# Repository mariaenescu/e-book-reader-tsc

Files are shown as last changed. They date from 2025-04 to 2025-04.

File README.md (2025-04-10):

Enescu Maria - 331CA

# OpenBook Project - E-Book Reader

OpenBook is a compact device designed for digital reading. Based on the ESP32-C6 microcontroller, OpenBook includes integrated Wi-Fi connectivity.
It features a 7.5" e-Paper display and an 1800mAh battery, offering extended battery life.

--- 

## 3D Visualizations
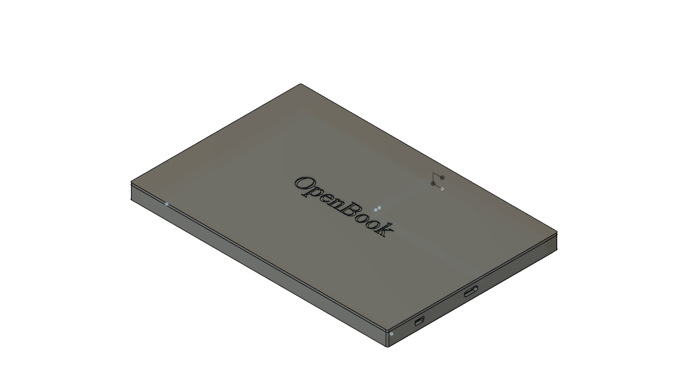
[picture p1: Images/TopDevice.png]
P1

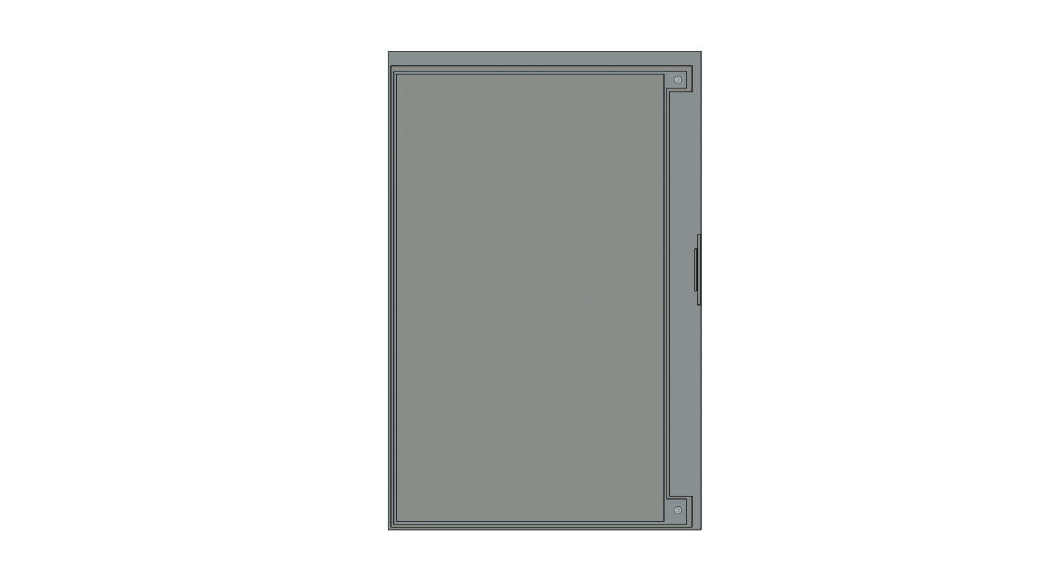
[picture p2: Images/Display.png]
P2

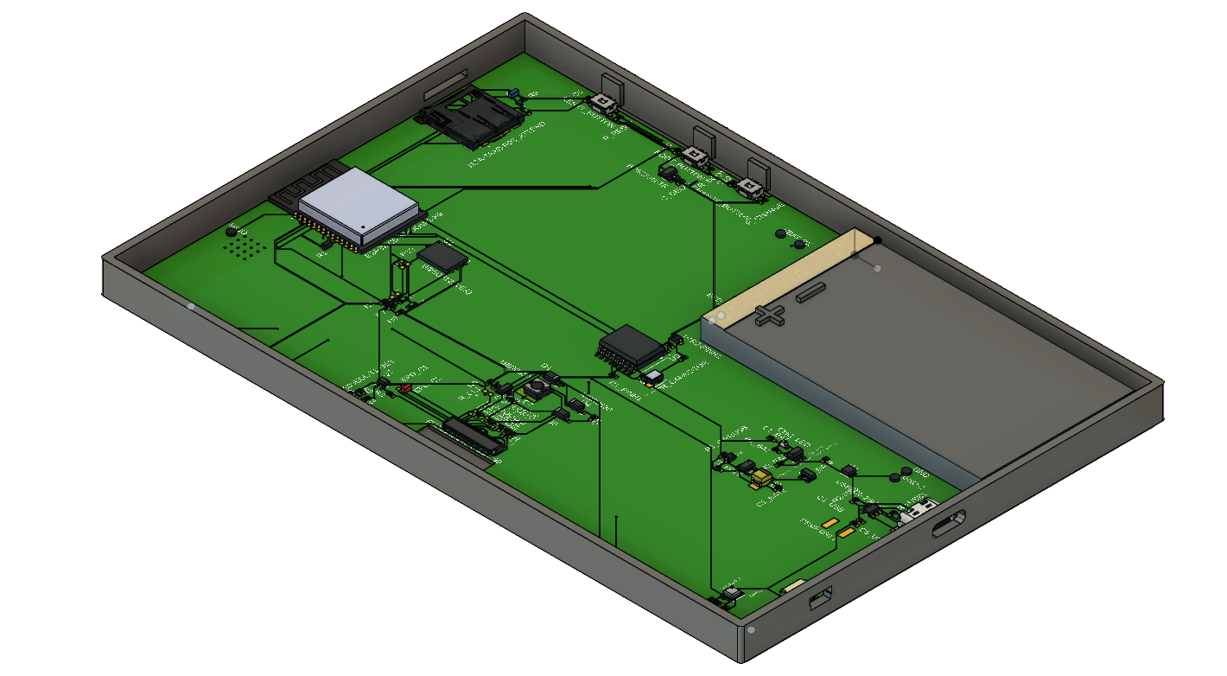
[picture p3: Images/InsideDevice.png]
P3


---
## Block Diagram
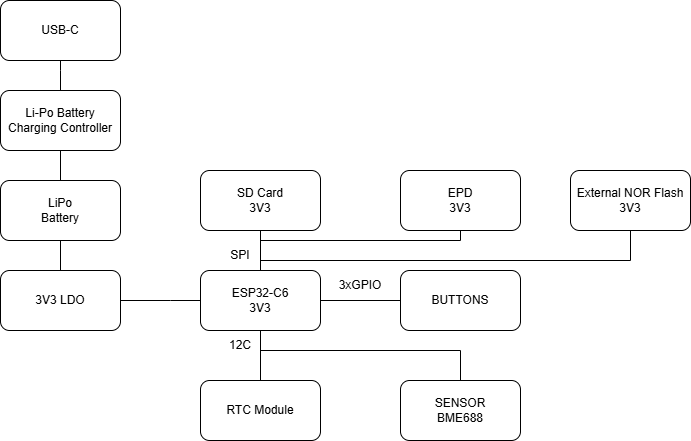
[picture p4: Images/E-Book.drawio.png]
Diagrama bloc


---

## Main Components Overview

**Microcontroller – ESP32-C6-WROOM-1-N8**  
Acts as the main processing unit of the system, responsible for wireless communication, power management, and control of all peripherals. It uses SPI, I2C, and GPIO interfaces to interact with external modules.

**E-Paper Display – 7.5” Waveshare**  
Displays e-book content using ultra-low power. It is controlled via SPI and connected through MOSI, MISO, SCK, CS, DC, RST, and BUSY pins.

**MicroSD Card – 112A-TAAR-R03**  
Used for storing e-books and data files. Communicates with the ESP32 via the SPI interface and supports FAT32 format up to 32GB.

**NOR Flash Memory – W25Q512JVEIQ**  
Provides external non-volatile memory for storing firmware or additional data. It connects via SPI and supports fast read/write operations.

**Real-Time Clock – DS3231SN**  
Ensures accurate timekeeping, even when the device is off. It uses the I2C protocol and provides a 32KHz output and interrupt signal.

**Environmental Sensor – BME688**  
Measures temperature, humidity, pressure, and gas levels. Communicates via I2C and is powered through a dedicated I2C power pin.

**Battery – Cellevia LP584174 (Li-Po 3.7V, 1800mAh)**  
Powers the system when disconnected from USB. Provides stable operation and extended autonomy.

**Power Management – MCP73831 & AMS1117**  
MCP73831 handles Li-Po charging via USB-C. AMS1117 regulates the output voltage to 3.3V required by the ESP32 and peripherals.

**USB-C Connector – USB4110-GF-A**  
Used for charging the battery and data transfer. Protected by ESD varistor (PFMF.050.1) and Schottky diode for reverse polarity.

**Buttons – Tactile Push Buttons (3x)**  
Used for boot, reset, and mode change. Connected to GPIOs for user input and state control.

---

## Bill of Materials
| Compound | Purchase | Datasheet |
|---|---|---|
| Buton | [Click here](https://componentsearchengine.com/prices/TSP1C-RA?manufacturer=KNITTER-SWITCH) | https://docs.rs-online.com/1fd0/0900766b80e2c247.pdf |
| Condensator 100nF | [Click here](https://ro.mouser.com/ProductDetail/KYOCERA-AVX/04026D104KAT2A?qs=LLG2yGGJ5NhILwMziGI8Xg%3D%3D) | https://www.mouser.com/catalog/supplier/library/pdf/AVXSurfaceMountCeramic.pdf |
| CPH3225A(C10_SUPERCAP) | [Click here](https://ro.mouser.com/ProductDetail/Seiko-Semiconductors/CPH3225A?qs=3etwrb1wR%252BhUOph6lAO7eg%3D%3D) | https://ro.mouser.com/datasheet/2/360/Seiko_Instruments_MicroBattery_E_20230330_2024Jan_-3561061.pdf |
| Condensator 4.7uF | [Click here](https://ro.mouser.com/ProductDetail/KEMET/C0402C475M7PACTU?qs=SzIX745sIXFB9Q9KfZhc4g%3D%3D) | https://ro.mouser.com/datasheet/2/447/KEM_C1006_X5R_SMD-3316465.pdf |
| Tantalum Condensator 100uF | [Click here](https://ro.mouser.com/ProductDetail/KYOCERA-AVX/TAJW107M010RNJ?qs=Wtp%252Bf%2FAeVqIH8v1VxV%252B1Rg%3D%3D) | https://ro.mouser.com/datasheet/2/40/TAJ-3165264.pdf |
| Condensator 1uF | [Click here](https://ro.mouser.com/ProductDetail/KYOCERA-AVX/04026D105KAT2A?qs=LLG2yGGJ5NgAzk5fb%252BnzGQ%3D%3D) | https://ro.mouser.com/datasheet/2/40/cx5r_KGM-3223198.pdf |
| Condensator 10uF | [Click here](https://www.digikey.com/en/products/detail/venkel/C0402X5R100-106MNP/12327194) | https://venkelecd.com/partnumber/datasheet/C0402X5R100-106MNP) |
| CHG_LED | [Click here](https://www.kingbrightusa.com/distyPNInv.asp?sltSearch=distyInv&match=1&txtPartNo=APHM1608ECT) | https://www.kingbrightusa.com/images/catalog/SPEC/APHM1608ECT.pdf |
| USBLC6-2SC6Y | [Click here](https://ro.mouser.com/ProductDetail/STMicroelectronics/USBLC6-2SC6Y?qs=gNDSiZmRJS%2FOgDexvXkdow%3D%3D) | https://ro.mouser.com/datasheet/2/389/usblc6_2sc6y-1852505.pdf |
| PGB1010603MR | [Click here](https://ro.mouser.com/ProductDetail/Littelfuse/PGB1010603MR?qs=gu7KAQ731URLg4GSnNNN7Q%3D%3D) | https://www.littelfuse.com/assetdocs/pulseguard-esd-suppressors-pgb1-datasheet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 |
| SD0805S020S1R0 | [Click here](https://ro.mouser.com/ProductDetail/KYOCERA-AVX/SD0805S020S1R0?qs=jCA%252BPfw4LHbpkAoSnwrdjw%3D%3D) | https://ro.mouser.com/datasheet/2/40/schottky-3165252.pdf |
| MBR0530 | [Click here](https://ro.mouser.com/ProductDetail/onsemi/MBR0530T1G?qs=3JMERSakeboS%2FFOxJUMWeg%3D%3D) | https://www.onsemi.com/download/data-sheet/pdf/mbr0530t1-d.pdf |
| Condensator 1uF/50V | [Click here](https://ro.mouser.com/ProductDetail/KYOCERA-AVX/06035D105MAT2A?qs=k4kUdCzLgS5%252BURKe1SOIeQ%3D%3D) | https://ro.mouser.com/datasheet/2/40/cx5r_KGM-3223198.pdf |
| Condensator 0.1uF/50V | [Click here](https://ro.mouser.com/ProductDetail/KYOCERA-AVX/04025C104JAT2A?qs=yqaQSyyJnNjAUYBPnTRwrw%3D%3D) | https://ro.mouser.com/datasheet/2/40/AutoMLCC-2952695.pdf |
| BD5229G-TR | [Click here](https://ro.mouser.com/ProductDetail/ROHM-Semiconductor/BD5229G-TR?qs=4kLU8WoGk0vvnhrrYwdszw%3D%3D) | https://fscdn.rohm.com/en/products/databook/datasheet/ic/power/voltage_detector/bd52xxg-e.pdf |
| XC6220A331MR-G | [Click here](https://ro.mouser.com/ProductDetail/Torex-Semiconductor/XC6220A331MR-G?qs=AsjdqWjXhJ8ZSWznL1J0gg%3D%3D) | https://ro.mouser.com/datasheet/2/760/xc6220-3371556.pdf |
| FH34SRJ-24S-0.5SH_99_ | [Click here](https://ro.mouser.com/ProductDetail/Hirose-Connector/FH34SRJ-24S-0.5SH99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) | https://ro.mouser.com/datasheet/2/185/FH34SRJ_24S_0_5SH_99__CL0580_1255_6_99_2DDrawing_0-1615044.pdf |
| USB4110-GF-A | [Click here](https://ro.mouser.com/ProductDetail/GCT/USB4110-GF-A?qs=KUoIvG%2F9IlYiZvIXQjyJeA%3D%3D) | https://ro.mouser.com/datasheet/2/837/GCT_USB4110_Product_Drawing___20k_cycles-3455479.pdf |
| QWIIC_RIGHT_ANGLE | [Click here](https://ro.mouser.com/ProductDetail/JST-Commercial/SM04B-SRSS-TBLFSN?qs=cdbOS8ANM9B3FdyA6cNU2A%3D%3D) | https://ro.mouser.com/datasheet/2/564/eSR_SZ-3476820.pdf |
| 112A-TAAR-R03_ATTEND | [Click here](https://www.tme.eu/ro/details/mcc-sdmicro/conectori-pentru-cartele/attend/112a-taar-r03/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) | https://www.attend.com.tw/data/download/file/112A-TAAR-R03.pdf |
| Bobina | [Click here](https://ro.mouser.com/ProductDetail/Wurth-Elektronik/744043680?qs=PGXP4M47uW6VkZq%252BkzjrHA%3D%3D) | https://www.we-online.com/components/products/datasheet/744043680.pdf |
| MCP73831 | [Click here](https://ro.mouser.com/ProductDetail/Microchip-Technology/MCP73831T-2ATI-OT?qs=yUQqVecv4qsZbioEUu%252B83g%3D%3D) | https://ro.mouser.com/datasheet/2/268/MCP73831_Family_Data_Sheet_DS20001984H-3441711.pdf |
| PFMF.050.1 | [Click here](https://ro.mouser.com/ProductDetail/Schurter/PFMF.050.2?qs=1auRipcfynCums5v1iucSA%3D%3D) | https://ro.mouser.com/datasheet/2/358/typ_PFMF-1275918.pdf |
| DMG2305UX-7 | [Click here](https://ro.mouser.com/ProductDetail/Diodes-Incorporated/DMG2305UX-7?qs=L1DZKBg7t5F%2FNBHrjfxC%252Bg%3D%3D) | https://www.diodes.com/assets/Datasheets/DMG2305UX.pdf |
| SI1308EDL-T1-GE3 | [Click here](https://ro.mouser.com/ProductDetail/Vishay-Semiconductors/SI1308EDL-T1-GE3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) | https://www.vishay.com/docs/63399/si1308edl.pdf |
| Rezistenta 10K | [Click here](https://www.digikey.com/en/products/detail/venkel/CR0402-10W-102JT/12332774) | https://data.venkel.com/documents/cr-series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.) |
| Rezistenta 200 | [Click here](https://ro.mouser.com/ProductDetail/Vishay-Beyschlag/MCS0402MD2000BE100?qs=3SvaY9RawMJNVte4F12%252BZQ%3D%3D) | https://www.vishay.com/docs/28952/mcs0402at-mct0603at-mcu0805at-mca1206at.pdf |
| Rezistenta 100K | [Click here](https://www.digikey.com/en/products/detail/venkel/CR0402-16W-1003FT/12328296) | https://octopart.com/datasheet/cr0402-16w-1003ft-venkel-16112934) |
| Rezistenta 2.2 | [Click here](https://www.digikey.com/en/products/detail/venkel/TFCR0402-16W-C-1002BT/12331302) | https://data.venkel.com/documents/tfcr-series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.) |
| Rezistenta 5K1 | [Click here](https://ro.mouser.com/ProductDetail/YAGEO/RT0402BRD075K1L?qs=gY0y7AQI9SOxpEAvlEsiTQ%3D%3D) | https://ro.mouser.com/datasheet/2/447/PYu_RT_1_to_0_01_RoHS_L_15-3461507.pdf |
| Rezistenta 2K | [Click here](https://ro.mouser.com/ProductDetail/Bourns/CR0402AFX-2001GLF?qs=GedFDFLaBXEKjamDtfYtIQ%3D%3D) | https://ro.mouser.com/datasheet/2/54/cr_a-1858337.pdf |
| Rezistenta 0.47 | [Click here](https://ro.mouser.com/ProductDetail/Vishay-Beyschlag/MMA02040C4707JB000?qs=YmMt7wOBEV42V6C1Rc7zpg%3D%3D) | https://www.vishay.com/docs/28713/melfprof.pdf |
| Rezistenta 15 | [Click here](https://ro.mouser.com/ProductDetail/YAGEO/RT0402FRE0715RL?qs=BXCcY9r%252B08DFFpLSkPOIqQ%3D%3D) | https://ro.mouser.com/datasheet/2/447/PYu_RT_1_to_0_01_RoHS_L_15-3461507.pdf |
| BME688 | [Click here](https://ro.mouser.com/ProductDetail/Bosch-Sensortec/BME688?qs=IS%252B4QmGtzzqQoVDscqwx3A%3D%3D) | https://ro.mouser.com/datasheet/2/783/bst_bme688_fl000-2307034.pdf |
| W25Q512JVEIQ | [Click here](https://ro.mouser.com/ProductDetail/Winbond/W25Q512JVEIQ?qs=l7cgNqFNU1jw6svr3at6tA%3D%3D) | https://ro.mouser.com/datasheet/2/949/Winbond_W25Q512JV_Datasheet-3240039.pdf |
| ESP32-C6-WROOM-1-N8 | [Click here](https://ro.mouser.com/ProductDetail/Espressif-Systems/ESP32-C6-WROOM-1-N8?qs=8Wlm6%252BaMh8ST02Gmwp74cw%3D%3D) | https://ro.mouser.com/datasheet/2/891/Espressif_ESP32_C6_WROOM_1__Datasheet_V0_1_PRELIMI-3239987.pdf |
| DS3231SN# | [Click here](https://ro.mouser.com/ProductDetail/Analog-Devices-Maxim-Integrated/DS3231SN?qs=1eQvB6Dk1vhUlr8%2FOrV0Fw%3D%3D) | https://ro.mouser.com/datasheet/2/609/DS3231-3421123.pdf |
| MAX17048G+T10 | [Click here](https://ro.mouser.com/ProductDetail/Analog-Devices-Maxim-Integrated/MAX17048G%2bT10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) | https://ro.mouser.com/datasheet/2/609/MAX17048_MAX17049-3469099.pdf |
---

## Hardware Functionality Description

The project uses the `ESP32-C6-WROOM-1-N8` microcontroller, which integrates **BLE 5** and **Wi-Fi 6** for fast and efficient communication.
The system is powered by a **3.7V Li-Po battery** with a capacity of 1800mAh (`Cellevia LP584174`).
Battery charging is managed by the `TP4056` module via a `USB-C` connector, and the constant `3.3V` required by the system is provided by an `AMS1117` voltage regulator.
The `ESP32-C6` microcontroller controls the entire system through standard **SPI**, **I2C**, and **GPIO** interfaces, as follows:
1. The `7.5" Waveshare e-Paper Display` (800x480 resolution) is connected via SPI.
2. The `SD Card` and `external NOR Flash` memory are also connected via SPI for data storage.
3. The `RTC (DS3231SN)` and `environmental sensor (BME688)` are connected via **I2C**, enabling precise real-time measurements.
4. **GPIO connections** allow control of the `RESET` and `BOOT` functions, and the **Qwiic/Stemma QT** interface supports additional sensor expansion.
5. For debugging, there are dedicated Test Pads for UART communication (`TX/RX`).

---

##  Pinii ESP32-C6
| Pin ESP32-C6 | GPIO | Job | Connected to |
|---|---|---|---|
| EN | - | RESET | Reset hardware |
| IO0 | GPIO0 | INT RTC | Intrerupere RTC |
| IO1 | GPIO1 | 32KHZ | Semnal 32kHz RTC |
| IO2 | GPIO2 | MISO | SPI MISO (Date citite) |
| IO3 | GPIO3 | EPD BUSY | Semnal ocupat Display  |
| IO4 | GPIO4 | SS_SD | Chip select SD Card |
| IO5 | GPIO5 | EPD_DC | Comanda/Date Display |
| IO6 | GPIO6 | SCK | SPI Clock |
| IO7 | GPIO7 | MOSI | SPI MOSI (Date trimise)|
| IO8 | GPIO8 | IO/BOOT | Boot mode selection |
| IO9 | GPIO9 | - | Neconectat |
| IO10 | GPIO10 | - | Neconectat |
| IO11 | GPIO11 | EPD_CS | Chip Select Display |
| IO12 | GPIO12 | FLASH_CS | Chip Select Flash |
| IO13 | GPIO13 | USB D- | Linie USB D- |
| IO14 | GPIO14 | USB D+ | Linie USB D+ |
| IO15 | GPIO15 | IO/CHANGE | Buton schimbare mod |
| IO16 | GPIO16/TX | TX | UART Debug TX |
| IO17 | GPIO17/RX | RX | UART Debug RX |
| IO18 | GPIO18 | RTC_RST | Reset RTC |
| IO19 | GPIO19 | I2C PW | Alimentare senzor I2C  |
| IO20 | GPIO20 | EPD_3V3_C | Control 3.3V Display |
| IO21 | GPIO21/SDA  | SDA | I2C Date |
| IO22 | GPIO22/SCL  | SCL | I2C Clock |
| IO23 | GPIO23 | EPD_RST | Reset Display |
---

## Project Implementation:
      
`The schematic` was created according to the requirement PDF, using symbols from the provided library and verified using 
the `ERC` file. Warnings were avoided, and remaining errors were accepted as non-critical.
During the `PCB` design phase, all components were placed exclusively on the `Top Layer`, following mechanical and dimensional recommendations.
Both the `ESP32 antenna area` and the `buttons` were cut out from the PCB outline.
`Routing` was performed using the Autorouter, with a 100% routing weight and minimum via size.
A `ground plane` was created on both layers (Bottom and Top).
`Via stitching` was added near the ESP32 component in a free area, avoiding routing traces.
Each component name is marked with `TopSilkscreen`.
Each component has an associated 3D model, either designed (TPs, battery, and display) or imported from external libraries.
The 3D models were created using exact dimensions from the provided datasheets and can be viewed in the `Images/` folder.
Later, I positioned the 3D model of the PCB, the battery, and the display inside the case.
A video has also been added in `Images/` to visualize the 3D placement of all components for the complete E-Book.

---

### Issues Encountered:

- After importing each 3D component, I noticed several routing errors and value mismatches appearing on the PCB—
  errors that did not exist before using `Push to 3D PCB`. After adding the 3D components, I attempted to re-route to fix these issues.
- I encountered problems with 3D component placement. Although all 3D models were imported, not all of them appeared on the 3D PCB.
- In **Fusion 360**, `Push to 3D PCB` sometimes desynchronized component labels and layers. Also, not all components kept their footprints aligned after 3D model imports, requiring manual corrections.
- I also had to ensure no 90° trace angles were present, per assignment constraints — which was hard to maintain while autorouting.

---

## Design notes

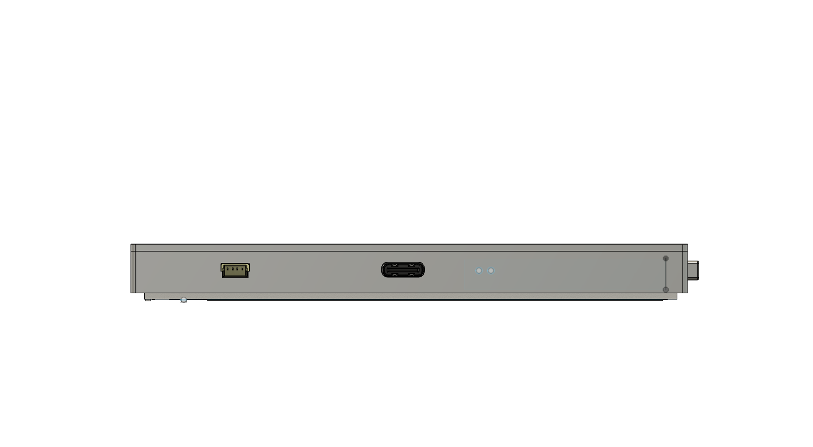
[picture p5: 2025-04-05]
Images/RightDevice.png

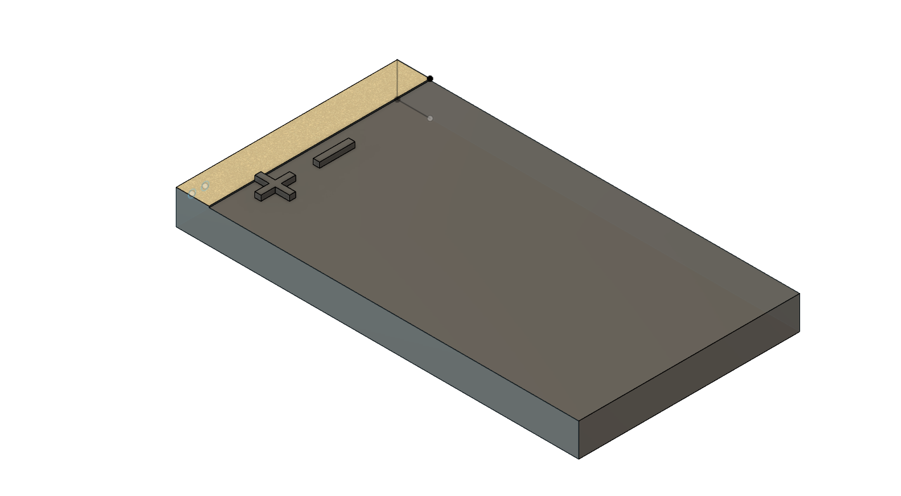
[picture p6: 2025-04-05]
Images/Battery.png

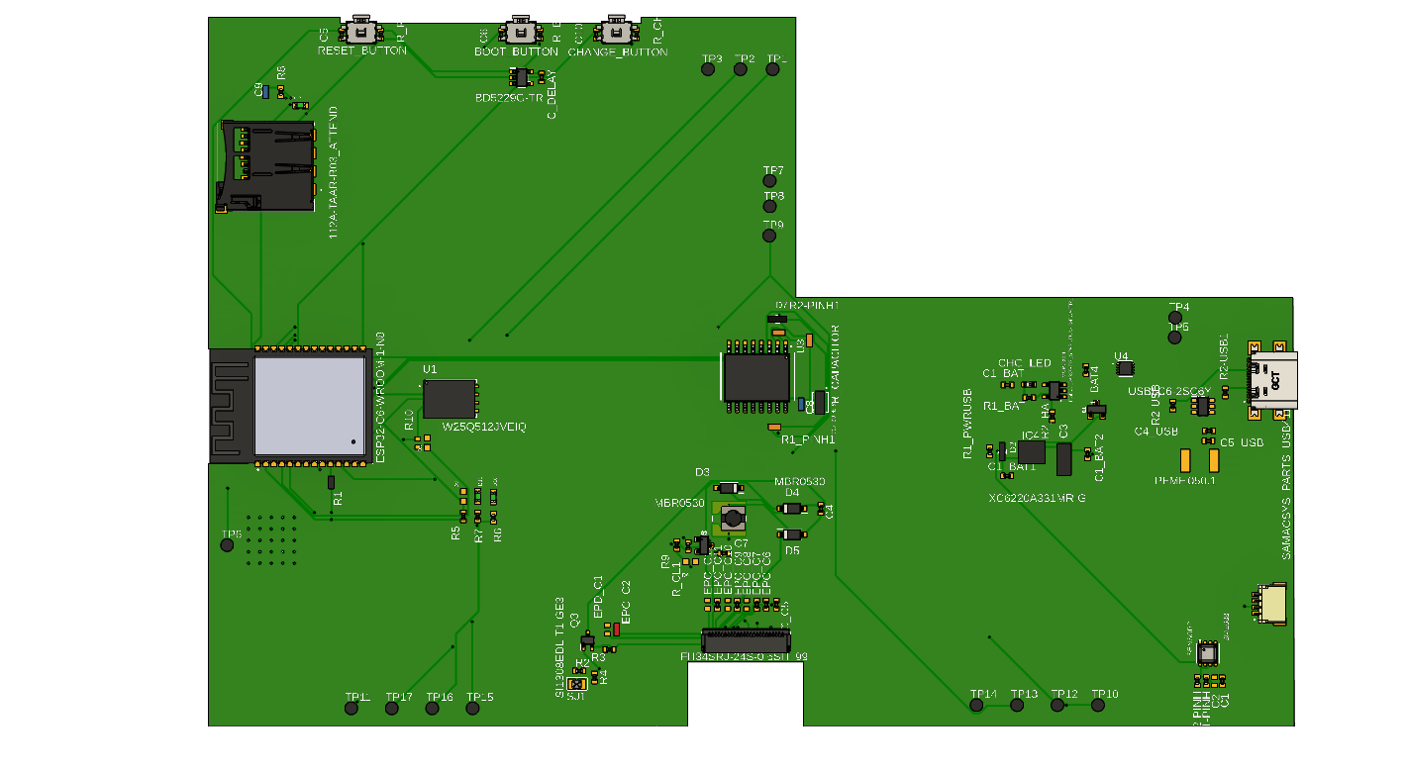
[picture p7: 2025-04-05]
Images/Board.png

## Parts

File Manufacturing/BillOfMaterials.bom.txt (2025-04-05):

Designator                      Comment Footprint
BOOT_BUTTON	51.42	111.33	180.00	BUTTON_CUSYOMV1	MYBUTTON
C1	161.49	9.58	90.00	100nF	EAGLE-LTSPICE_C0402
C10	63.28	111.11	270.00	100nF	EAGLE-LTSPICE_C0402
C10_SUPERCAP	98.35	53.34	270.00	CPH3225A	CAPCP3225X100N
C1_BAT	127.80	56.08	0.00	4.7uF	EAGLE-LTSPICE_C0402
C1_BAT1	127.73	41.82	0.00	4.7uF	EAGLE-LTSPICE_C0402
C1_BAT2	140.37	45.22	270.00	4.7uF	EAGLE-LTSPICE_C0402
C1_BAT4	140.11	58.42	270.00	4.7uF	EAGLE-LTSPICE_C0402
C2	160.27	9.58	90.00	100nF	EAGLE-LTSPICE_C0402
C3	136.69	44.40	270.00	100uF	RCL_CT3528
C4	98.52	36.64	270.00	4.7uF/25V	EAGLE-LTSPICE_C0402
C4_USB	159.40	48.90	180.00	100nF	EAGLE-LTSPICE_C0402
C5	23.33	111.06	270.00	1uF	EAGLE-LTSPICE_C0402
C5_USB	159.31	47.30	180.00	4.7uF	EAGLE-LTSPICE_C0402
C6	48.35	111.11	270.00	100nF	EAGLE-LTSPICE_C0402
C7	83.33	29.66	0.00	10uF	EAGLE-LTSPICE_C0402
C8	95.42	53.06	270.00	100nF	EAGLE-LTSPICE_C0402
C9	11.40	102.06	270.00	100nF	EAGLE-LTSPICE_C0402
CHANGE_BUTTON	66.44	111.33	180.00	BUTTON_CUSYOMV1	MYBUTTON
CHG_LED	131.14	56.15	90.00		ADAFRUIT_CHIP-LED0603
C_DELAY	54.70	104.34	270.00	100nF	EAGLE-LTSPICE_C0402
D1	158.48	52.72	0.00	USBLC6-2SC6Y	SOT95P280X145-6N
D10	47.13	38.50	90.00	PGB1010603MR	DIOC1608X36N
D11	44.71	38.60	90.00	PGB1010603MR	DIOC1608X36N
D12	16.89	99.90	0.00	PGB1010603MR	DIOC1608X36N
D2	126.95	45.61	90.00	ESP32_WROVER_AVX---SD0805S020S1R0_AVX_SD0805S020S1R0_0_0AVX_SD0805S020S1R0_0_0	ESP32_WROVER_AVX---SD0805S020S1R0_AVX_SD0805S020S1R0_0
D3	84.04	39.90	180.00	MBR0530	SOD3716X135N
D4	93.98	36.70	180.00	MBR0530	SOD3716X135N
D5	94.02	32.58	0.00	MBR0530	SOD3716X135N
D6	78.11	28.32	0.00	PGB1010603MR	DIOC1608X36N
D7	91.70	66.41	0.00	SD0805S020S1R0	ESP32_WROVER_AVX---SD0805S020S1R0_AVX_SD0805S020S1R0_0
D8	36.76	47.02	90.00	PGB1010603MR	DIOC1608X36N
D9	42.45	38.60	90.00	PGB1010603MR	DIOC1608X36N
EPC_C10	83.91	21.62	270.00	1uF/50V	ESP32_WROVER_EAGLE-LTSPICE_C0402
EPC_C11	82.29	21.62	270.00	1uF/50V	ESP32_WROVER_EAGLE-LTSPICE_C0402
EPC_C12	80.75	21.62	270.00	1uF/50V	ESP32_WROVER_EAGLE-LTSPICE_C0402
EPC_C2	65.02	17.70	270.00	1uF/50V	ESP32_WROVER_EAGLE-LTSPICE_C0402
EPC_C5	91.53	21.60	270.00	1uF/50V	ESP32_WROVER_EAGLE-LTSPICE_C0402
EPC_C6	89.94	21.60	270.00	1uF/50V	ESP32_WROVER_EAGLE-LTSPICE_C0402
EPC_C7	88.45	21.60	270.00	1uF/50V	ESP32_WROVER_EAGLE-LTSPICE_C0402
EPC_C8	86.86	21.60	270.00	1uF/50V	ESP32_WROVER_EAGLE-LTSPICE_C0402
EPC_C9	85.38	21.58	270.00	1uF/50V	ESP32_WROVER_EAGLE-LTSPICE_C0402
EPD_C1	66.49	17.68	270.00	1uF/50V	ESP32_WROVER_EAGLE-LTSPICE_C0402
IC1	51.55	104.32	0.00	BD5229G-TR	SOT95P280X125-5N
IC4	131.59	45.52	0.00	XC6220A331MR-G	SOT95P280X120-5N
J1	86.75	16.02	0.00	FH34SRJ-24S-0.5SH_99_	FH34SRJ24S05SH99
J2	168.26	56.79	90.00	SAMACSYS_PARTS_USB4110-GF-A	SAMACSYS_PARTS_USB4110GFA
J3	168.67	21.73	90.00	QWIIC_RIGHT_ANGLE	JST04_1MM_RA
J4	11.57	90.33	270.00	112A-TAAR-R03_ATTEND	112ATAARR03ATTEND
L1	84.07	35.05	270.00	68uH	IND_4828-WE-TPC_WRE
MCP73831	135.16	55.19	90.00	ESP32_WROVER_SPARKFUN-IC-POWER_MCP73831	ESP32_WROVER_SPARKFUN-IC-POWER_SOT23-5
PFMF.050.1	157.94	44.20	180.00	ESP32C6_VARISTORCN1812	ESP32C6_VARISTOR_CT/CN1812
Q1	141.76	52.21	0.00	20V/4.2A/52mΩ/1.4W	ESP32_WROVER_SPARKFUN-DISCRETESEMI_SOT23-3
Q2	80.23	30.86	270.00	20V/4.2A/52mΩ/1.4W	ESP32_WROVER_SPARKFUN-DISCRETESEMI_SOT23-3
Q3	61.95	15.98	90.00	SI1308EDL-T1-GE3	SOT65P210X110-3N
R1	21.69	40.76	270.00	10K	ESP32_WROVER_EAGLE-LTSPICE_R0402
R1-PINH	158.98	9.60	90.00	10K	ESP32_WROVER_EAGLE-LTSPICE_R0402
R10	35.27	46.96	90.00	10K	ESP32_WROVER_EAGLE-LTSPICE_R0402
R1_BAT	131.21	54.08	0.00	200	ESP32_WROVER_EAGLE-LTSPICE_R0402
R1_PINH1	91.26	49.50	0.00		ESP32_WROVER_EAGLE-LTSPICE_R0402
R1_PWRUSB	125.01	45.64	90.00	100K	ESP32_WROVER_EAGLE-LTSPICE_R0402
R2	60.59	11.20	0.00	2.2	ESP32_WROVER_EAGLE-LTSPICE_R0402
R2-PINH	157.59	9.60	90.00	10K	ESP32_WROVER_EAGLE-LTSPICE_R0402
R2-PINH1	91.90	64.30	0.00		ESP32_WROVER_EAGLE-LTSPICE_R0402
R2-USB	153.73	52.85	270.00	5k1	ESP32_WROVER_EAGLE-LTSPICE_R0402
R2-USB1	161.95	54.92	90.00	5k1	ESP32_WROVER_EAGLE-LTSPICE_R0402
R2_BAT	134.82	51.18	90.00	2K	ESP32_WROVER_EAGLE-LTSPICE_R0402
R3	65.35	14.56	0.00	0.47	ESP32_WROVER_EAGLE-LTSPICE_R0402
R4	63.01	10.16	90.00	10K	ESP32_WROVER_EAGLE-LTSPICE_R0402
R5	42.43	35.46	270.00	10K	ESP32_WROVER_EAGLE-LTSPICE_R0402
R6	47.15	35.26	270.00	10K	ESP32_WROVER_EAGLE-LTSPICE_R0402
R7	44.67	35.46	270.00	10K	ESP32_WROVER_EAGLE-LTSPICE_R0402
R8	13.79	102.06	90.00	10K	ESP32_WROVER_EAGLE-LTSPICE_R0402
R9	75.91	30.96	90.00	10K	ESP32_WROVER_EAGLE-LTSPICE_R0402
RESET_BUTTON	26.43	111.35	180.00	BUTTON_CUSYOMV1	MYBUTTON
R_BOOT	54.47	111.11	90.00	10K	ESP32_WROVER_EAGLE-LTSPICE_R0402
R_CAPACITOR	96.71	63.04	270.00	15	ESP32_WROVER_EAGLE-LTSPICE_R0402
R_CHANGE	69.58	111.14	90.00	10K	ESP32_WROVER_EAGLE-LTSPICE_R0402
R_CL1	77.71	30.78	90.00	10K	ESP32_WROVER_EAGLE-LTSPICE_R0402
R_RESET	29.48	111.11	90.00	10K	ESP32_WROVER_EAGLE-LTSPICE_R0402
SENSOR2	159.23	13.92	90.00	BME688	ESP32_WROVER_BME680_PSON80P300X300X100-8N
SJ1	60.22	9.12	0.00		SJ
TP1	90.96	105.64	0.00	TPTP20R	TP20R
TP10	141.99	5.84	0.00	TPTP20R	TP20R
TP11	24.84	5.34	0.00	TPTP20R	TP20R
TP12	135.64	5.84	0.00	TPTP20R	TP20R
TP13	129.29	5.84	0.00	TPTP20R	TP20R
TP14	122.94	5.84	0.00	TPTP20R	TP20R
TP15	43.89	5.34	0.00	TPTP20R	TP20R
TP16	37.54	5.34	0.00	TPTP20R	TP20R
TP17	31.19	5.34	0.00	TPTP20R	TP20R
TP2	85.88	105.64	0.00	TPTP20R	TP20R
TP3	80.80	105.64	0.00	TPTP20R	TP20R
TP4	154.12	66.64	0.00	TPTP20R	TP20R
TP5	154.04	63.54	0.00	TPTP20R	TP20R
TP6	5.36	30.94	0.00	TPTP20R	TP20R
TP7	90.49	88.12	0.00	TPTP20R	TP20R
TP8	90.51	84.12	0.00	TPTP20R	TP20R
TP9	90.43	79.52	0.00	TPTP20R	TP20R
U1	40.49	53.96	0.00	W25Q512JVEIQ	SON127P600X800X80-9N
U2	18.39	52.74	90.00	ESP32-C6-WROOM-1-N8	XCVR_ESP32-C6-WROOM-1-N8
U3	88.55	57.40	270.00	DS3231SN#	SOIC127P1032X265-16N
U4	146.28	58.65	0.00	MAX17048G+T10	SON50P200X200X80-9N

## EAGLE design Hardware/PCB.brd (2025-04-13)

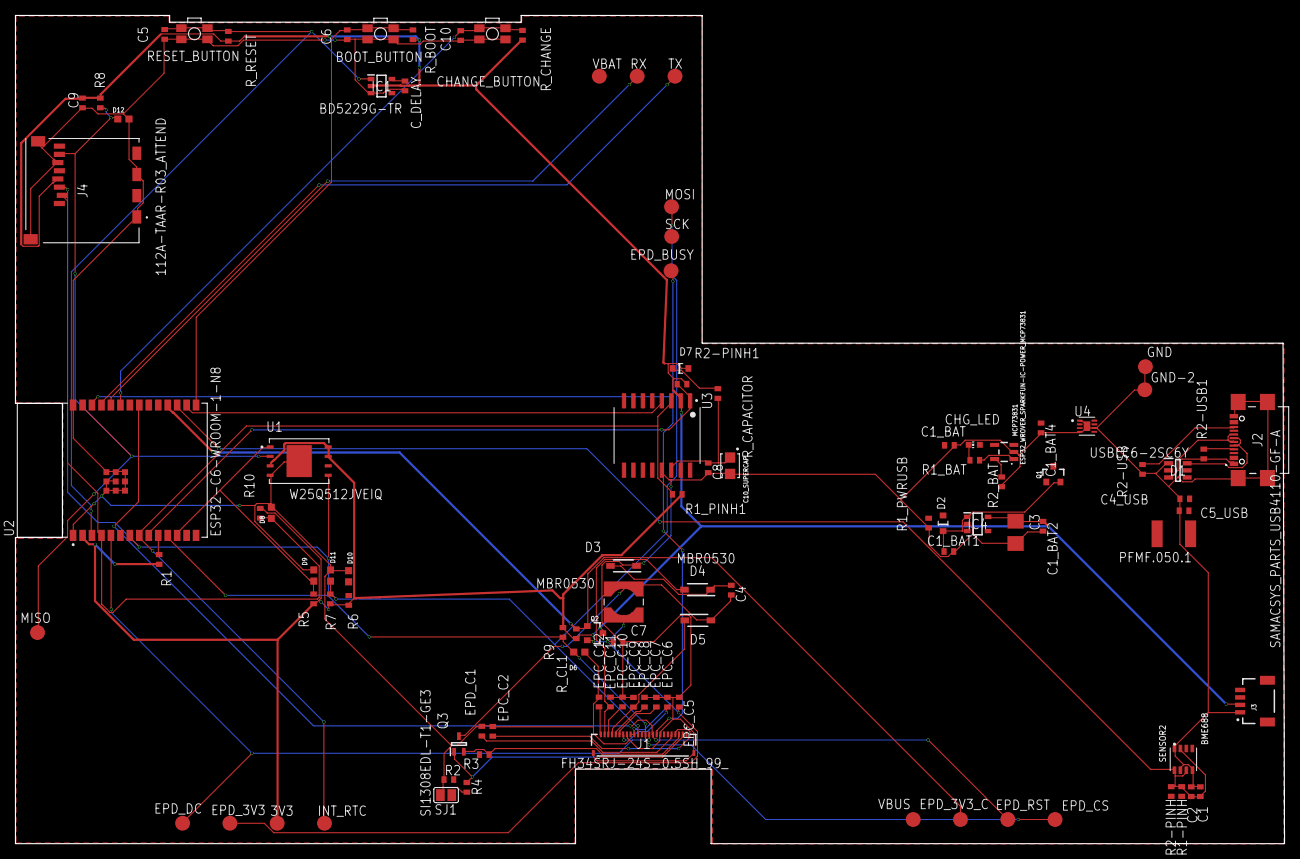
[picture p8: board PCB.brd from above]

Board: 2 copper layers, 170.4 x 111.2 mm, 103 parts (0 on the bottom side), 46 nets.

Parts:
3V3: TPTP20R; TP20R
BOOT_BUTTON: BUTTON_CUSYOMV1; MYBUTTON
C1, C2, C4_USB, C6, C8, C9, C10: 100nF; EAGLE-LTSPICE_C0402
C1_BAT, C1_BAT1, C1_BAT2, C1_BAT4, C5_USB: 4.7uF; EAGLE-LTSPICE_C0402
C3: 100uF; RCL_CT3528
C4: 4.7uF/25V; EAGLE-LTSPICE_C0402
C5: 1uF; EAGLE-LTSPICE_C0402
C7: 10uF; EAGLE-LTSPICE_C0402
C10_SUPERCAP: CPH3225A; CAPCP3225X100N
CHANGE_BUTTON: BUTTON_CUSYOMV1; MYBUTTON
CHG_LED: ADAFRUIT_CHIP-LED0603
C_DELAY: 100nF; EAGLE-LTSPICE_C0402
D1: USBLC6-2SC6Y; SOT95P280X145-6N
D2: ESP32_WROVER_AVX---SD0805S020S1R0_AVX_SD0805S020S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; ESP32_WROVER_AVX---SD0805S020S1R0_AVX_SD0805S020S1R0_0
D3, D4, D5: MBR0530; SOD3716X135N
D6, D8, D9, D10, D11, D12: PGB1010603MR; DIOC1608X36N
D7: SD0805S020S1R0; ESP32_WROVER_AVX---SD0805S020S1R0_AVX_SD0805S020S1R0_0
EPC_C2, EPC_C5, EPC_C6, EPC_C7, EPC_C8, EPC_C9, EPC_C10, EPC_C11, EPC_C12: 1uF/50V; ESP32_WROVER_EAGLE-LTSPICE_C0402
EPD_3V3, EPD_3V3_C: TPTP20R; TP20R
EPD_BUSY: TPTP20R; TP20R
EPD_C1: 1uF/50V; ESP32_WROVER_EAGLE-LTSPICE_C0402
EPD_CS: TPTP20R; TP20R
EPD_DC: TPTP20R; TP20R
EPD_RST: TPTP20R; TP20R
GND: TPTP20R; TP20R
GND-2: TPTP20R; TP20R
IC1: BD5229G-TR; SOT95P280X125-5N
IC4: XC6220A331MR-G; SOT95P280X120-5N
INT_RTC: TPTP20R; TP20R
J1: FH34SRJ-24S-0.5SH_99_; FH34SRJ24S05SH99
J2: SAMACSYS_PARTS_USB4110-GF-A; SAMACSYS_PARTS_USB4110GFA
J3: QWIIC_RIGHT_ANGLE; JST04_1MM_RA
J4: 112A-TAAR-R03_ATTEND; 112ATAARR03ATTEND
L1: 68uH; IND_4828-WE-TPC_WRE
MCP73831: ESP32_WROVER_SPARKFUN-IC-POWER_MCP73831; ESP32_WROVER_SPARKFUN-IC-POWER_SOT23-5
MISO: TPTP20R; TP20R
MOSI: TPTP20R; TP20R
PFMF.050.1: ESP32C6_VARISTORCN1812; ESP32C6_VARISTOR_CT/CN1812
Q1, Q2: 20V/4.2A/52mΩ/1.4W; ESP32_WROVER_SPARKFUN-DISCRETESEMI_SOT23-3
Q3: SI1308EDL-T1-GE3; SOT65P210X110-3N
R1, R1-PINH, R1_PINH1, R2-PINH, R2-PINH1, R4, R5, R6, R7, R8, R9, R10: 10K; ESP32_WROVER_EAGLE-LTSPICE_R0402
R1_BAT: 200; ESP32_WROVER_EAGLE-LTSPICE_R0402
R1_PWRUSB: 100K; ESP32_WROVER_EAGLE-LTSPICE_R0402
R2: 2.2; ESP32_WROVER_EAGLE-LTSPICE_R0402
R2-USB, R2-USB1: 5k1; ESP32_WROVER_EAGLE-LTSPICE_R0402
R2_BAT: 2K; ESP32_WROVER_EAGLE-LTSPICE_R0402
R3: 0.47; ESP32_WROVER_EAGLE-LTSPICE_R0402
RESET_BUTTON: BUTTON_CUSYOMV1; MYBUTTON
RX: TPTP20R; TP20R
R_BOOT: 10K; ESP32_WROVER_EAGLE-LTSPICE_R0402
R_CAPACITOR: 15; ESP32_WROVER_EAGLE-LTSPICE_R0402
R_CHANGE: 10K; ESP32_WROVER_EAGLE-LTSPICE_R0402
R_CL1: 10K; ESP32_WROVER_EAGLE-LTSPICE_R0402
R_RESET: 10K; ESP32_WROVER_EAGLE-LTSPICE_R0402
SCK: TPTP20R; TP20R
SENSOR2: BME688; ESP32_WROVER_BME680_PSON80P300X300X100-8N
SJ1: SJ
TX: TPTP20R; TP20R
U1: W25Q512JVEIQ; SON127P600X800X80-9N
U2: ESP32-C6-WROOM-1-N8; XCVR_ESP32-C6-WROOM-1-N8
U3: DS3231SN#; SOIC127P1032X265-16N
U4: MAX17048G+T10; SON50P200X200X80-9N
VBAT: TPTP20R; TP20R
VBUS: TPTP20R; TP20R

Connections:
3V3: 3V3.TP, C1_BAT2.1, C3.+, C9.1, D7.2, IC1.2, IC4.5, J3.2, J4.P4, Q2.3, R1.2, R1_PINH1.2, R2-PINH1.2, R5.2, R6.2, R7.2, R8.2, R9.2, R10.2, R_BOOT.1, R_CHANGE.1, R_CL1.1, R_RESET.1, U1.3, U1.7, U1.8, U2.2, U3.2
12C_PW: C1.1, C2.1, R1-PINH.2, R2-PINH.2, SENSOR2.2, SENSOR2.6, SENSOR2.8, U2.17
32KHZ: R2-PINH1.1, U2.9, U3.1
DN: D1.6, J2.A7, J2.B7
DP: D1.3, J2.A6, J2.B6
EPD_3V3: C7.1, EPC_C5.2, EPD_3V3.TP, J1.15, J1.16, L1.2, Q2.2
EPD_3V3_C: EPD_3V3_C.TP, Q2.1, R_CL1.2, U2.18
EPD_BUSY: EPD_BUSY.TP, J1.9, U2.26
EPD_CS: D6.1, EPD_CS.TP, J1.12, R9.1, U2.11
EPD_DC: EPD_DC.TP, J1.11, U2.5
EPD_RST: EPD_RST.TP, J1.10, U2.21
FLASH_CS: D9.1, R5.1, U1.1, U2.12
GDR: J1.2, Q3.1, R4.2
GND: BOOT_BUTTON.1, BOOT_BUTTON.2, C1.2, C1_BAT.2, C1_BAT1.2, C1_BAT2.2, C1_BAT4.2, C2.2, C3.-, C4_USB.2, C5.2, C5_USB.2, C6.2, C7.2, C8.2, C9.2, C10.2, C10_SUPERCAP.2, CHANGE_BUTTON.1, CHANGE_BUTTON.2, C_DELAY.2, D1.1, D3.1, D6.2, D8.2, D9.2, D10.2, D11.2, D12.2, EPC_C2.1, EPC_C5.1, EPC_C6.1, EPC_C7.1, EPC_C8.1, EPC_C9.1, EPC_C10.1, EPC_C11.1, EPC_C12.1, EPD_C1.1, GND.TP, GND-2.TP, IC1.3, IC4.2, J1.8, J1.17, J1.MP1, J1.MP2, J2.A1, J2.A12, J2.B1, J2.B12, J2.MP1, J2.MP2, J2.MP3, J2.MP4, J3.1, J4.G1, J4.G2, J4.G3, J4.G4, J4.P6, MCP73831.2, R1_PWRUSB.1, R2.1, R2-USB.2, R2-USB1.1, R2_BAT.1, R4.1, RESET_BUTTON.1, RESET_BUTTON.2, SENSOR2.1, SENSOR2.5, SENSOR2.7, SJ1.1, U1.4, U1.9, U2.1, U2.28, U2.29_1, U2.29_2, U2.29_3, U2.29_4, U2.29_5, U2.29_6, U2.29_7, U2.29_8, U2.29_9, U3.13, U4.1, U4.4, U4.6, U4.9
GPIO8: R1.1, U2.10
INT_RTC: INT_RTC.TP, R1_PINH1.1, U2.8, U3.3
IO/BOOT: BOOT_BUTTON.3, BOOT_BUTTON.4, C6.1, R_BOOT.2, U2.15
IO/CHANGE: C10.1, CHANGE_BUTTON.3, CHANGE_BUTTON.4, R_CHANGE.2, U2.23
MISO: D12.1, J4.P7, MISO.TP, R8.1, U1.2, U2.27
MOSI: D11.1, J1.14, J4.P3, MOSI.TP, R7.1, U1.5, U2.7
unnamed: C1_BAT1.1, D2.1, IC4.1, IC4.3, Q1.2
unnamed: J2.B5, R2-USB.1
unnamed: J2.A5, R2-USB1.2
unnamed: C_DELAY.1, IC1.5
unnamed: C4.1, D3.2, D4.1
unnamed: MCP73831.1, R1_BAT.2
unnamed: CHG_LED.C, R1_BAT.1
unnamed: MCP73831.5, R2_BAT.2
unnamed: EPC_C12.2, J1.24
unnamed: D7.1, R_CAPACITOR.1
unnamed: EPC_C10.2, J1.22
unnamed: EPC_C8.2, J1.20
unnamed: EPC_C7.2, J1.19
unnamed: EPC_C6.2, J1.18
unnamed: EPC_C2.2, J1.5
unnamed: EPD_C1.2, J1.4
PREVGH: D5.1, EPC_C9.2, J1.21
PREVGL: D4.2, EPC_C11.2, J1.23
RESE: J1.3, Q3.2, R3.2
RESET: C5.1, IC1.1, RESET_BUTTON.3, RESET_BUTTON.4, R_RESET.2, U2.3
RTC_RST: U2.16, U3.4
RX: RX.TP, U2.24
SRC: C4.2, D5.2, L1.1, Q3.3
SS_SD: D8.1, J4.P2, R10.1, U2.4
TX: TX.TP, U2.25
VRTC: C8.1, C10_SUPERCAP.1, R_CAPACITOR.2, U3.14

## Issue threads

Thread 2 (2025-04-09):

[DOC] Add images to README

bogdanstoicasn, 2025-04-09:
The  `Images/` directory contains useful renders and photos of the device, but they are not currently linked in the `README.md`.

To improve visual understanding of the hardware design, please include the most relevant images in the `README`(e.g., battery, screen, board, etc.). You can check this **stackoverflow** question: https://stackoverflow.com/questions/14494747/how-to-add-images-to-readme-md-on-github

Closed 2025-04-10.

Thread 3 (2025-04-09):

[DOC] Add brief description for key components in README

bogdanstoicasn, 2025-04-09:
The `README` would benefit from a short description of the main components used in the design(e.g., NOR Flash, RTC, SD Card, etc.).

For each of these, add a short sentence or two explaining their purpose and how they interface with the main controller(e.g., I2C, SPI, USART, etc.).

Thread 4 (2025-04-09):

[DOC] Expand design decisions and implementation notes

bogdanstoicasn, 2025-04-09:
The `README` includes sections about design decisions and encountered problems, which is great — but they are currently very brief.

Please consider expanding this sections with more details about:

- Constraints you had to work around

-  Challenges during the schematic or layout design

- Tool limitations or workarounds: If **Fusion360** imposed any limitations or needed specific handling(optional).

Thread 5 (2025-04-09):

[PCB] Rename test pads for clarity

bogdanstoicasn, 2025-04-09:
The test pads are currently named in a generic way (e.g., TP4, TP5, etc.). t would be more helpful if the test pads were named according to their function(e.g., TP1-RX) o make it easier to identify their role during testing.

This change will improve the clarity of the design and help anyone working with the board understand the purpose of each test pad.

Closed 2025-04-10.

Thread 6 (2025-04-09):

[PCB] VBAT test pad not connected

bogdanstoicasn, 2025-04-09:
The VBAT test pad appears to be placed on the PCB but is not connected to the VBAT net.

Please route the VBAT signal to this test pad so it can be used for measuring battery voltage, debugging and power behaviour monitoring.

Closed 2025-04-12.

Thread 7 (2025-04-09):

[PCB] Power traces should be at least 0.3mm width

bogdanstoicasn, 2025-04-09:
Power traces (e.g. VCC, 3V3, VBAT) should be routed with a minimum width of 0.3 mm as per the design constraints.
This is important for handling current safely and avoiding voltage drops.

Closed 2025-04-10.

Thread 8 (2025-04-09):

[PCB] Resistor labels near buttons are cut off in silkscreen

bogdanstoicasn, 2025-04-09:
The labels for the 3 resistors near the buttons are being cut off in the silkscreen layer.
The text is split in half and is not fully visible.

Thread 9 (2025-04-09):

[PCB] Resistors and capacitors near buttons overlap with button 3D model

bogdanstoicasn, 2025-04-09:
The resistors and capacitors placed near the buttons are overlapping with the 3D representation of the buttons. This can cause issues with the button functionality and component placement in the final assembly.

Closed 2025-04-10.

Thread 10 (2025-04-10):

[SCH] Unspecified resistor values in BME sensor section

bogdanstoicasn, 2025-04-10:
Two resistors(`R2-PINH1`, `R1_PINH1`) in the RTC Module section are missing specified values in the schematic. This may be an unintentional omission and should be reviewed for completeness.

Closed 2025-04-12.

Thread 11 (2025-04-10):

[PCB] 90-degree angle in **I2C_PW** trace

bogdanstoicasn, 2025-04-10:
The **I2C_PW** line contains a 90-degree angle. It is generally recommended to avoid 90-degree trace angles for improved signal integrity and manufacturability.

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

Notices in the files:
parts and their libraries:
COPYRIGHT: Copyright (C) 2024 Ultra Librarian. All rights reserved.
